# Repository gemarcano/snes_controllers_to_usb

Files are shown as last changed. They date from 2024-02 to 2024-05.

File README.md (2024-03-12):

# SNES Controllers to USB

This project contains the hardware design files and firmware used to build a 4
SNES controller hub to USB. At its core the board uses a Raspberry Pi Pico W
(could technically also be a regular Raspberry Pi Pico, but I have not tried
this) to poll the SNES controllers and manage USB communications with the host.

The design files are made using KiCAD, and the firmware is written in C++ using
the pico-sdk and FreeRTOS.

## Layout

The toplevel files are the hardware design files.

The software is in the `firmware/` directory. This has its own README.md.

The `graphics/` directory contains schematics and PCB diagrams in
easier-to-access formats for human use.

## Licenses

See the LICENSE files in the top level directory and in the `firmware/` folder
for more details.

In summary, the hardware files are released under the "CERN Open Hardware
Licence Version 2 - Weakly Reciprocal" license, and the software is
dual-licensed under the LGPL-2.1 or later and GPL-2.0 or later.

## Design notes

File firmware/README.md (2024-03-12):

# SNES Controllers to USB Firmware

## Building

This uses [FreeRTOS-Kernel](https://github.com/FreeRTOS/FreeRTOS-Kernel.git)
and the [pico-sdk](https://github.com/raspberrypi/pico-sdk.git).

pico-sdk needs some patches provided by these PRs:
 - [pico-sdk #1530](https://github.com/raspberrypi/pico-sdk/pull/1530)
 - [pico-sdk #1635](https://github.com/raspberrypi/pico-sdk/pull/1635)

And the tinyusb library in the pico-sdk (lib/tinyusb) needs this patch as well:
 - [tinyusb #2474](https://github.com/hathach/tinyusb/pull/2474)

After applying the patches, the build process is similar to a normal pico-sdk
application

```
mkdir build
cd build
cmake ../ -DPICO_SDK_PATH=[path-to-pico-sdk] \
  -DPICO_BOARD=pico_w -DCMAKE_BUILD_TYPE=[Debug|Release|RelWithDebInfo] \
  -DFREERTOS_KERNEL_PATH=[path-to-FreeRTOS-Kernel] -GNinja ninja
```

## Installing

```
# Reset board into programming mode by holding down bootsel
# and pressing the reset button
picotool load -f snes_controllers_to_usb.uf2
picotool reboot # Or just press the reset button
```

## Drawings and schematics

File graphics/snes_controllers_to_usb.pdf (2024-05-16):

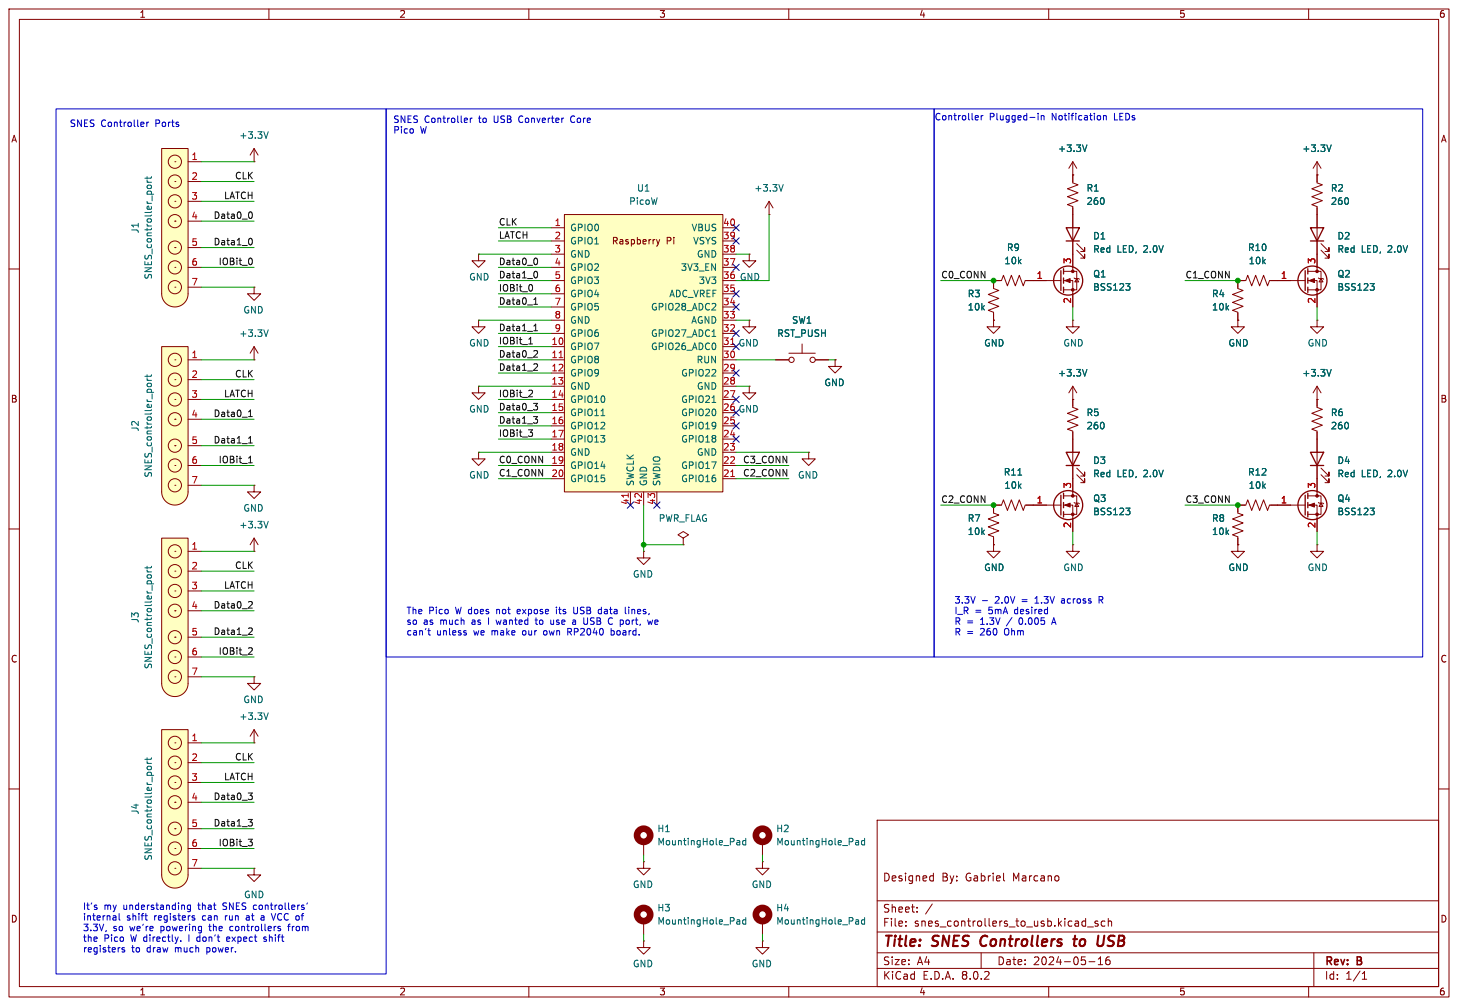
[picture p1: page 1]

The Pico W does not expose its USB data lines, so as much as I wanted to use a USB C port, we

can't unless we make our own RP2040 board.

Id: 1/1 Title: SNES Controllers to USB

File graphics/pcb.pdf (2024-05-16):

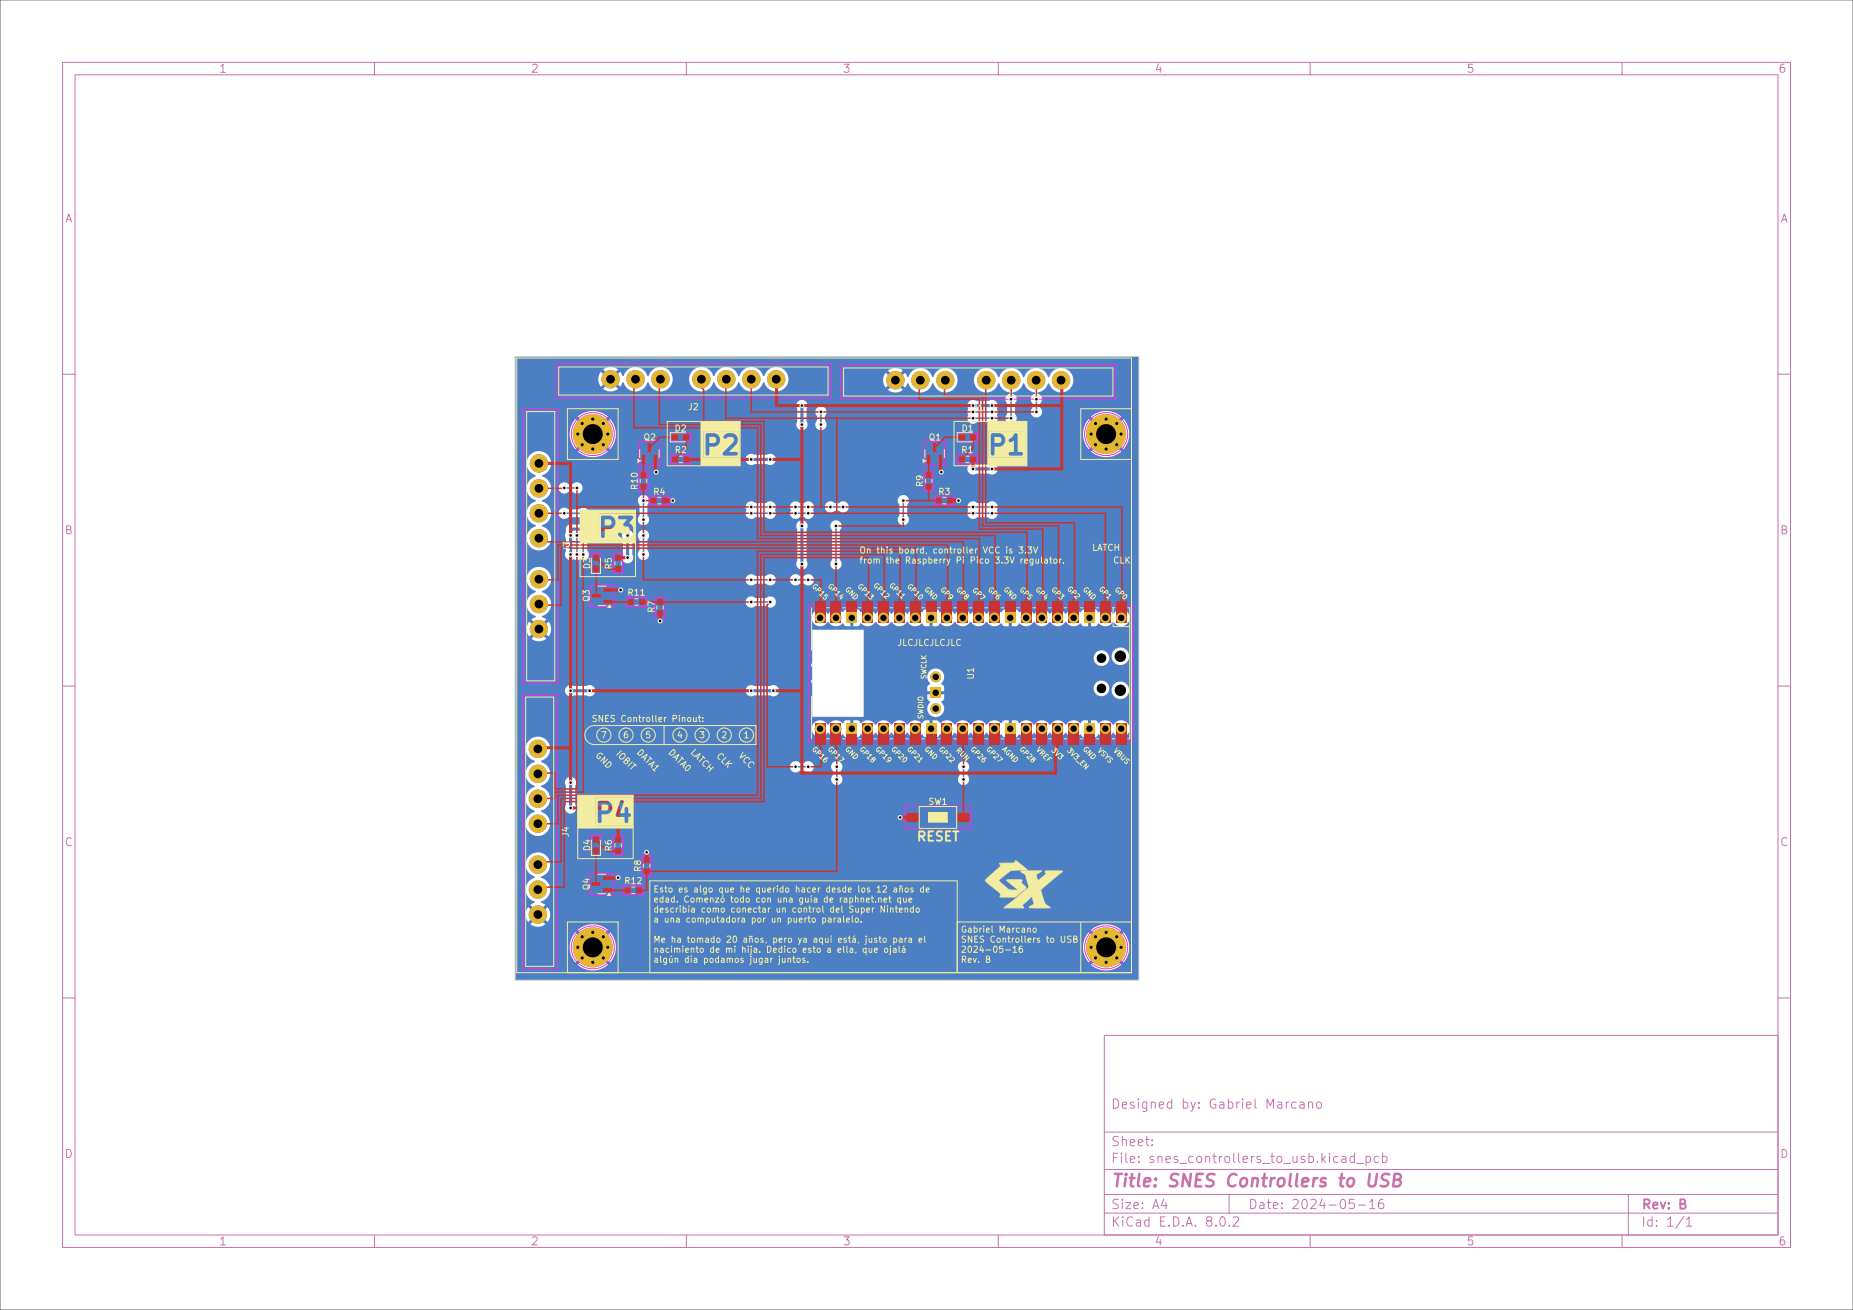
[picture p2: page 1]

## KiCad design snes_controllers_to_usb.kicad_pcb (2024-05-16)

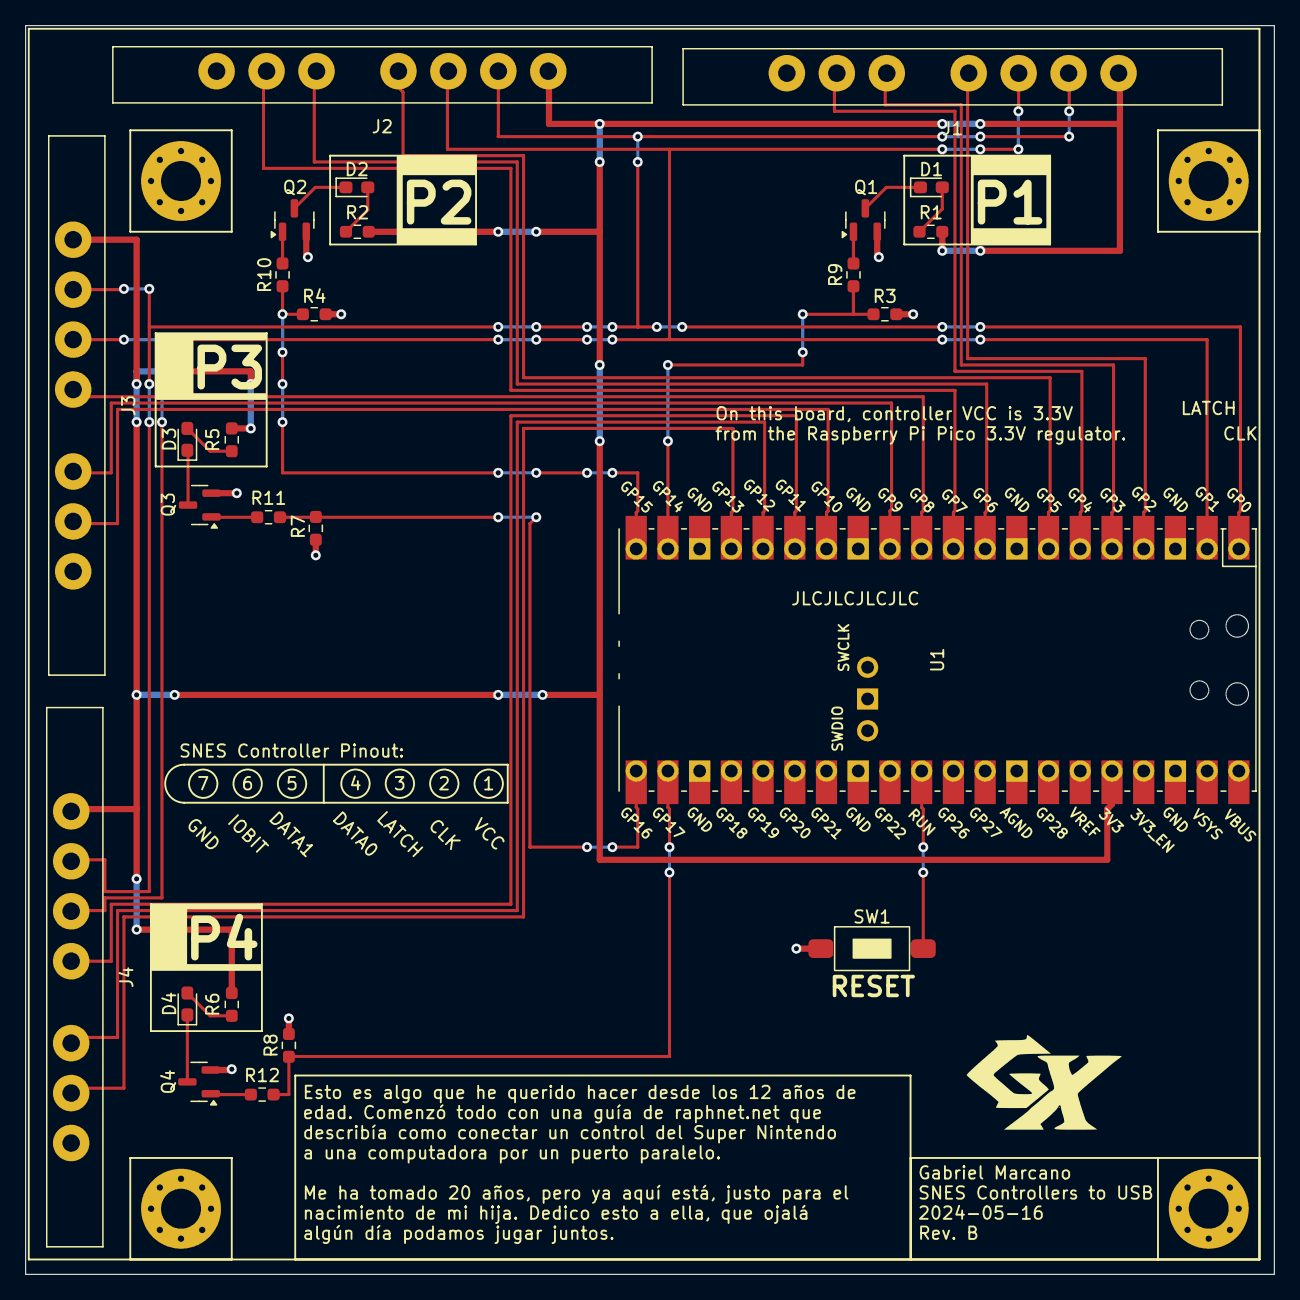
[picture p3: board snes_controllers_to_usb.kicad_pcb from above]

Board: 2 copper layers, 100.0 x 100.0 mm, 30 parts (0 on the bottom side), 33 nets.

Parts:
D1, D2, D3, D4: Red LED, 2.0V; LED_0603_1608Metric_Pad1.05x0.95mm_HandSolder
H1, H2, H3, H4: MountingHole_Pad; MountingHole_3.2mm_M3_Pad_Via
J1, J2, J3, J4: SNES_controller_port; SNES_CONTROLLER_PORT_FEMALE_SHORT
Q1, Q2, Q3, Q4: BSS123; SOT-23
R1, R2, R5, R6: 260; R_0603_1608Metric_Pad0.98x0.95mm_HandSolder
R3, R4, R7, R8, R9, R10, R11, R12: 10k; R_0603_1608Metric_Pad0.98x0.95mm_HandSolder
SW1: RST_PUSH; PTS636_SM50_SMTR_LFS
U1: PicoW; RPi_PicoW_SMD_TH

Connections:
+3.3V: J1.1, J2.1, J3.1, J4.1, R1.1, R2.1, R5.1, R6.1, U1.36 (3V3)
/C0_CONN: R3.1, R9.1, U1.19 (GPIO14)
/C1_CONN: R4.1, R10.1, U1.20 (GPIO15)
/C2_CONN: R7.1, R11.1, U1.21 (GPIO16)
/C3_CONN: R8.1, R12.1, U1.22 (GPIO17)
/CLK: J1.2, J2.2, J3.2, J4.2, U1.1 (GPIO0)
/Data0_0: J1.4, U1.4 (GPIO2)
/Data0_1: J2.4, U1.7 (GPIO5)
/Data0_2: J3.4, U1.11 (GPIO8)
/Data0_3: J4.4, U1.15 (GPIO11)
/Data1_0: J1.5, U1.5 (GPIO3)
/Data1_1: J2.5, U1.9 (GPIO6)
/Data1_2: J3.5, U1.12 (GPIO9)
/Data1_3: J4.5, U1.16 (GPIO12)
/IOBit_0: J1.6, U1.6 (GPIO4)
/IOBit_1: J2.6, U1.10 (GPIO7)
/IOBit_2: J3.6, U1.14 (GPIO10)
/IOBit_3: J4.6, U1.17 (GPIO13)
/LATCH: J1.3, J2.3, J3.3, J4.3, U1.2 (GPIO1)
GND: H1.1, H2.1, H3.1, H4.1, J1.7, J2.7, J3.7, J4.7, Q1.2 (S), Q2.2 (S), Q3.2 (S), Q4.2 (S), R3.2, R4.2, R7.2, R8.2, SW1.1, U1.3 (GND), U1.8 (GND), U1.13 (GND), U1.18 (GND), U1.23 (GND), U1.28 (GND), U1.33 (AGND), U1.38 (GND), U1.42 (GND)
unnamed: D1.2 (A), R1.2
unnamed: D1.1 (K), Q1.3 (D)
unnamed: D2.2 (A), R2.2
unnamed: D2.1 (K), Q2.3 (D)
unnamed: D3.2 (A), R5.2
unnamed: D3.1 (K), Q3.3 (D)
unnamed: D4.2 (A), R6.2
unnamed: D4.1 (K), Q4.3 (D)
unnamed: Q1.1 (G), R9.2
unnamed: Q2.1 (G), R10.2
unnamed: Q3.1 (G), R11.2
unnamed: Q4.1 (G), R12.2
unnamed: SW1.2, U1.30 (RUN)

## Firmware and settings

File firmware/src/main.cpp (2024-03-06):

// SPDX-License-Identifier: GPL-2.0-or-later OR LGPL-2.1-or-later
// SPDX-FileCopyrightText: Gabriel Marcano, 2024
/// @file

#include <sctu/log.h>
#include <sctu/usb.h>
#include <sctu/cli_task.h>
#include <sctu/watchdog.h>
#include <sctu/cdc_device.h>
#include <sctu/controller.h>
#include <sctu/pio_controllers.h>

#include <hardware/structs/mpu.h>

#include <tusb_config.h>
#include <tusb.h>
#include <bsp/board_api.h>

#include <FreeRTOS.h>
#include <queue.h>
#include <task.h>

#include <cstdio>

using sctu::sys_log;

static void print_callback(std::string_view str)
{
	printf("syslog: %.*s\r\n", str.size(), str.data());
}

constexpr const std::array<int, 4> led_gpios { 14, 15, 16, 17 };

// FreeRTOS task to handle polling controller and sending HID reports
static void hid_task(void*)
{
	TickType_t last = xTaskGetTickCount();
	sctu::pio_controllers controllers(pio0);

	// Initialize LED GPIOs
	for (int led: led_gpios)
	{
		gpio_init(led);
		gpio_set_dir(led, true);
	}

	std::array<sctu::controller, 4> last_state = {};
	for (;;)
	{
		vTaskDelayUntil(&last, pdMS_TO_TICKS(10));
		const std::array<sctu::controller, 4> state = controllers.poll();
		// Keep track of the number of controllers configured, used to index
		// tinyusb devices
		uint8_t controller_ready = 0;
		for (uint8_t i = 0; i < 4; ++i)
		{
			// Update USB controller state if there's a change
			if (last_state[i].connected != state[i].connected)
			{
				if (state[i].connected)
					usb_enable_controller(1 << i);
				else
					usb_disable_controller(1 << i);
				gpio_put(led_gpios[i], state[i].connected);
			}

			// Only bother updating the tinyusb report if tinyusb is ready and
			// we're connected.
			if (state[i].connected && tud_hid_n_ready(controller_ready))
			{
				// Remote wakeup only if it's suspended, and a button is pressed
				if (tud_suspended() && (state[i].x || state[i].y || state[i].buttons))
				{
					// Host must allow waking up from this device for this to work
					tud_remote_wakeup();
				}

				// Only send a report if the data has changed
				else if (last_state[i] != state[i])
				{
					// Our report only has 3 bytes, don't assume the struct with the data has
					// no padding, and don't use the no padding directive for structs-- last
					// thing I want to deal with is misaligned data access on ARM
					uint8_t buffer[3];
					buffer[0] = state[i].x;
					buffer[1] = state[i].y;
					buffer[2] = state[i].buttons;
					tud_hid_n_report(controller_ready, 0, &buffer, sizeof(buffer));
				}
				controller_ready++;
			}
			last_state[i] = state[i];
		}
	}
}

// FreeRTOS task to handle USB tasks
static void usb_device_task(void*)
{
	tusb_init();
	for(;;)
	{
		tud_task();
		// tud_cdc_connected() must be called in the same task as tud_task, as
		// an internal data structure is shared without locking between both
		// functions. See https://github.com/hathach/tinyusb/issues/1472
		// As a workaround, use an atomic variable to get the result of this
		// function, and read from it elsewhere
		sctu::cdc.update();
		taskYIELD();
	}
}

static void initialize_mpu()
{
	mpu_hw->ctrl = 5; // enable mpu with background default map
	mpu_hw->rbar = (0x0 & ~0xFFu)| M0PLUS_MPU_RBAR_VALID_BITS | 0;
	mpu_hw->rasr =
		1             // enable region
		| (0x7 << 1)  // size 2^(7 + 1) = 256
		| (0 << 8)    // Subregion disable-- don't disable any
		| 0x10000000; // Disable instruction fetch, disallow all
}

static void init_cpu_task(void* val)
{
	std::atomic_bool *cpu_init = reinterpret_cast<std::atomic_bool*>(val);
	initialize_mpu();
	*cpu_init = true;
	vTaskDelete(nullptr);
	for(;;);
}

static void init_task(void*)
{
	std::array<std::atomic_bool, 2> cpu_init = {};
	xTaskCreateAffinitySet(
		init_cpu_task,
		"sctu_cpu0_init",
		configMINIMAL_STACK_SIZE,
		&cpu_init[0],
		tskIDLE_PRIORITY+1,
		1 << 0,
		nullptr);

	xTaskCreateAffinitySet(
		init_cpu_task,
		"sctu_cpu1_init",
		configMINIMAL_STACK_SIZE,
		&cpu_init[1],
		tskIDLE_PRIORITY+1,
		1 << 1,
		nullptr);

	// Wait until CPU init tasks are done
	while(!cpu_init[0] || !cpu_init[1])
	{
		taskYIELD();
	}

	// We're not calling board_init() since for our configuration, all it is
	// really doing is initializing UART, which... we're not using at all.
	sctu::initialize_watchdog_tasks();
	sys_log.register_push_callback(print_callback);

	// Anything USB related needs to be on the same core-- just use core 2
	xTaskCreateAffinitySet(
		usb_device_task,
		"sctu_usb",
		configMINIMAL_STACK_SIZE*2,
		nullptr,
		tskIDLE_PRIORITY+1,
		1 << 1,
		nullptr);

	xTaskCreateAffinitySet(
		hid_task,
		"sctu_controller",
		configMINIMAL_STACK_SIZE,
		nullptr,
		tskIDLE_PRIORITY+1,
		1 << 1,
		nullptr);

	// CLI doesn't need to be in the same core as USB...
	xTaskCreateAffinitySet(
		sctu::cli_task,
		"sctu_cli",
		configMINIMAL_STACK_SIZE*2,
		nullptr,
		tskIDLE_PRIORITY+1,
		1 << 0,
		nullptr);

	// ...and kill this init task as it's done.
	vTaskDelete(nullptr);
	for(;;);
}

int main()
{
	// Alright, based on reading the pico-sdk, it's pretty much just a bad idea
	// to do ANYTHING outside of a FreeRTOS task when using FreeRTOS with the
	// pico-sdk... just do all required initialization in the init task
	xTaskCreateAffinitySet(
		init_task,
		"sctu_init",
		configMINIMAL_STACK_SIZE,
		nullptr,
		tskIDLE_PRIORITY+1,
		(1 << 0) | (1 << 1),
		nullptr);

	vTaskStartScheduler();
	for(;;);
	return 0;
}

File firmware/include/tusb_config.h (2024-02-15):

/*
 * The MIT License (MIT)
 *
 * Copyright (c) 2019 Ha Thach (tinyusb.org)
 *
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
 */

#ifndef _TUSB_CONFIG_H_
#define _TUSB_CONFIG_H_

#ifdef __cplusplus
 extern "C" {
#endif

//--------------------------------------------------------------------
// COMMON CONFIGURATION
//--------------------------------------------------------------------

// defined by board.mk
#ifndef CFG_TUSB_MCU
  #error CFG_TUSB_MCU must be defined
#endif

// RHPort number used for device can be defined by board.mk, default to port 0
#ifndef BOARD_DEVICE_RHPORT_NUM
  #define BOARD_DEVICE_RHPORT_NUM     0
#endif

// RHPort max operational speed can defined by board.mk
// Default to max (auto) speed for MCU with internal HighSpeed PHY
#ifndef BOARD_DEVICE_RHPORT_SPEED
  #define BOARD_DEVICE_RHPORT_SPEED   OPT_MODE_DEFAULT_SPEED
#endif

// Device mode with rhport and speed defined by board.mk
#if   BOARD_DEVICE_RHPORT_NUM == 0
  #define CFG_TUSB_RHPORT0_MODE     (OPT_MODE_DEVICE | BOARD_DEVICE_RHPORT_SPEED)
#elif BOARD_DEVICE_RHPORT_NUM == 1
  #define CFG_TUSB_RHPORT1_MODE     (OPT_MODE_DEVICE | BOARD_DEVICE_RHPORT_SPEED)
#else
  #error "Incorrect RHPort configuration"
#endif

// This examples use FreeRTOS
// FIXME apparently this is inserted by the pico-sdk
//#define CFG_TUSB_OS               OPT_OS_FREERTOS

#ifndef CFG_TUSB_DEBUG
#define CFG_TUSB_DEBUG           0
#endif

/* USB DMA on some MCUs can only access a specific SRAM region with restriction on alignment.
 * Tinyusb use follows macros to declare transferring memory so that they can be put
 * into those specific section.
 * e.g
 * - CFG_TUSB_MEM SECTION : __attribute__ (( section(".usb_ram") ))
 * - CFG_TUSB_MEM_ALIGN   : __attribute__ ((aligned(4)))
 */
#ifndef CFG_TUSB_MEM_SECTION
#define CFG_TUSB_MEM_SECTION
#endif

#ifndef CFG_TUSB_MEM_ALIGN
#define CFG_TUSB_MEM_ALIGN          __attribute__ ((aligned(4)))
#endif

//--------------------------------------------------------------------
// DEVICE CONFIGURATION
//--------------------------------------------------------------------

#ifndef CFG_TUD_ENDPOINT0_SIZE
#define CFG_TUD_ENDPOINT0_SIZE    64
#endif

//------------- CLASS -------------//
#define CFG_TUD_HID               4
#define CFG_TUD_CDC               1
#define CFG_TUD_MSC               0
#define CFG_TUD_MIDI              0
#define CFG_TUD_VENDOR            0

// HID buffer size Should be sufficient to hold ID (if any) + Data
#define CFG_TUD_HID_EP_BUFSIZE    16

// CDC FIFO size of TX and RX
#define CFG_TUD_CDC_RX_BUFSIZE   (TUD_OPT_HIGH_SPEED ? 512 : 64)
#define CFG_TUD_CDC_TX_BUFSIZE   (TUD_OPT_HIGH_SPEED ? 512 : 64)

// CDC Endpoint transfer buffer size, more is faster
#define CFG_TUD_CDC_EP_BUFSIZE   (TUD_OPT_HIGH_SPEED ? 512 : 64)

#ifdef __cplusplus
 }
#endif

#endif /* _TUSB_CONFIG_H_ */

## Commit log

2024-02-10 Initial commit
    - Already at revision A*, minor text changes to text on PCB silk
    screen, renaming project from singular "snes controller" to plural
    "snes controllers"
    [snes_controller_to_usb-B_Cu.gbl, snes_controller_to_usb-B_Mask.gbs, snes_controller_to_usb-B_Paste.gbp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]
2024-02-10 Add schematic and overall PCB pdfs
2024-02-15 Add beginnings of software implementation
    - Software is based off my wifi pc remote button code, as well as my
    old SNES STM32 controller converter code for the TinyUSB descriptor.
    - This code relies on the following upstream PRs:
    - https://github.com/raspberrypi/pico-sdk/pull/1530
    - https://github.com/FreeRTOS/FreeRTOS-Kernel/pull/991
    - https://github.com/raspberrypi/pico-sdk/pull/1635
2024-02-15 C++ify usb_descriptors, dynamic # of HID devices
    - Convert usb_descriptors to C++ to make it just overall easier to read
    - Much easier endian and utf16le handling
    - Add experimental support for reloading USB configuration if the
    number of controllers changes. Sometimes I'm seeing a crash on the
    debugger with an error of "ep %d %s was already available"
    - Support up to 4 controllers.
    - Tweak test code to produce random data for 2 controllers.
    [main.cpp, tusb_config.h]
2024-02-16 Enable MPU to catch null-dereference
    - ROM exists at address 0x0, and while that's a valid memory to want to
    access... I don't need it. Set up the MPUs for both cores to block
    the first 256 bytes. This caught 2 bugs in TinyUSB :)
    [main.cpp]
2024-02-17 Copy wifi management from pc_remote_button
    - Copy the improved wifi management code from pc_remote_button here,
    for further testing
    - Move wifi code to its own file
    - Copy status handling from pc_remote_button, more internet status now
    printed
2024-02-19 wifi: Check for lwip flags as well for state
    - Apparently the pico cyw43 function can return JOIN status when LWIP
    reports the link is down. Check both to see if we need to reset the
    connection.
2024-02-19 usb: compute ID from pico ID
2024-02-23 Switch to heap_4
    - There's a race condition with heap_3 FreeRTOS between heap_3 and
    pico-sdk mutex implementation. See
    https://github.com/raspberrypi/pico-sdk/issues/1646 for more
    information.
2024-02-27 Tested PIO implementation with oscillopscope
    - Found that I needed to change the default UART pins to not GPIO0 and
    1, as I'm using those for CLK and LATCH.
    - Added basic framework of a class to interact with the PIO control
2024-02-29 Change transistor gate resistors to 1kOhm
    - Currently by using both 10kOhm resistors for pulldown and the current
    limiting resistor, it effectively makes a voltage divider, which sets
    the gate voltage a little low. Change the current limiting resistor
    to 1kOhm to make the gate voltage be 90% of the input voltage, which
    should be good enough.
    [snes_controllers_to_usb.kicad_sch]
2024-02-29 Fix PIO timing for P2-4, add LED support
    - Timing for secondary PIO program was completely off, fix it and make
    each pulse take 15 cycles.
    - Add support for the LED GPIOs and have them turn on and off depending
    on the state of the controller detection.
    [main.cpp]
2024-02-29 Address some concerns cppcheck found
    - Mostly setting single-argument constructors to explicit
    - Make sure to assign member variables when using default constructors
    - Use the proper PRIxx macros for printf'ing cstdint types
    - Use `zu` for printing size_t
2024-02-29 Enable MPU first, reduce timer task stack size
2024-03-07 Don't use std::format, uses 40kB of code!
    - std::format is really nice, but it uses an obscene amount of code
    (likely because a lot of it is dead, but can't be eliminated due to a
    lack of LTO since the pico-sdk doesn't support it). Manually generate
    the log strings instead.
    - Annoyingly enough, it looks like my newlib doesn't understand %zu for
    printf. Use %u instead (yes, not exactly the same, but should work
    for all rp2040s).
2024-05-16 Update to KiCAD 8, revision B, move some resistors
    - Update schematic and PCB to KiCAD8
    - Move R7, R8, R9, and R10 so they no longer make a voltage divider at
    the transistor bases
    - Updated drawings
    - Replaced SNES port footprint with one where the silkscreen doesn't go
    past the end of the board
    [snes_controllers_to_usb.kicad_pcb, snes_controllers_to_usb.kicad_sch]
